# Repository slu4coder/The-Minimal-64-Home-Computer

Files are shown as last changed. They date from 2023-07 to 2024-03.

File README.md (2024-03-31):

# Legacy: Minimal 64 Home Computer

See https://github.com/slu4coder/Minimal-64x4-Home-Computer for the most recent version.

Quick note: This is a free and non-commercial project. I am in no way associated with any activies selling this as a product.
Any such activity represents a license violation. Individual licenses apply for hardware and software parts. Please refer to
appropriate documentations for detailed licensing information.



Here is my take on 80's home computer magic: The most computer from the least logic or the shortest way from TTL to Space Invaders.

Introductory videos: https://www.youtube.com/watch?v=3zGTsi4AYLw, https://www.youtube.com/watch?v=FJsnKu20ch8

Reference manual: https://docs.google.com/document/d/1e4hL9Z7BLIoUlErWgJOngnSMYLXjfnsZB9BtlwhTC6U/edit?usp=sharing

Visit my YouTube channel: https://www.youtube.com/channel/UCXYQcMpUBT3aaQKfmAVJNow

Like this project and want to give something back? https://www.paypal.me/carstenherting

FEATURES

● Only 56 74HCxx logic ICs, 1x 6C1008 SRAM, 4x 39SF0x0 FLASH, BUT NO MICROCONTROLLER!

● Textbook 'Von-Neumann' architecture, 8-bit data bus, 16-bit address bus, 24 control signals

● 64KB RAM, 512KB FLASH SSD with file system (format, load, save, dir, delete)

● Monochrome VGA output 400 x 240 pixels, PS/2, expansion slot and serial UART port

● 8MHz system clock, 6MHz CPU clock with 0.84Mips (2x Commodore 64)

● 128 instructions including conditional branching, subroutines, stack and word operations

● 2 data registers A, B plus two more "software" registers X, Y

● ALU supporting ADD, SUBTRACT, AND, OR with 3 flags (negative, carry and zero)

● Full native tool-chain: MinOS, text editor, assembler, fast Python-like interpreter 'MIN'

● Emulator, cross-assembler (Windows) and classic games (TETRIS clone, Space Invaders clone)

● Open-source emulators in JAVA/PROCESSING and JAVASCRIPT/p5.js https://editor.p5js.org/slu4coder/full/aOUivViNt

See "CHANGE LOG" for a brief summary of the relevant updates.
  
Have fun!

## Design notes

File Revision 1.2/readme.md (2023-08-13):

# Hardware Revision 1.2

For the bill of materials (BOM) please refer to the chapter 'Hardware' of the 'Minimal 64 Reference Manual': https://docs.google.com/document/d/1e4hL9Z7BLIoUlErWgJOngnSMYLXjfnsZB9BtlwhTC6U/edit?usp=sharing

Jim Bailey has also shared his MOUSER parts list.

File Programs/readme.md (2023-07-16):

# Native Software of the 'Minimal 64 Home Computer'

o '.asm' denotes assembly source code.

o '.min' denotes 'Min' source code.

o 'manual.txt' is displayed by the 'Minimal 64' upon entering 'show manual'.

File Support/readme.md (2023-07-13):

# Supporting Tool-Chain

o Cross-platform assemblers

o Emulators

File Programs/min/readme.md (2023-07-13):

# 'Min' Programs

'Min' is a Python-like high-level programming language running natively on the 'Minimal 64'.
The interpreter 'min.asm' assembly source code is located in the '../asm' section.

See 'Min's EBNF Language Definition.txt' for more information.

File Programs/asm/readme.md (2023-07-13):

# Assembly Programs

Assembly code (OS, native tool-chain, games, demos) written for the 'Minimal 64'.

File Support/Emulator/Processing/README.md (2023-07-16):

# Emulator (Java/Processing)

This is the portable 'Java/Processing' version of the 'Minimal 64 Home Computer' emulator.

The emulator is using German keyboard layout. For customizing do the following:

o Uncomment the first line of the 'keyPressed()' function in the source code: println(keyCode);

o Run the emulator and press any keys under question.

o Note the corresponding keyCodes printed out in Processing's console window.

o Identify the corresponding PS/2 scan codes (see section 'PS/2 Keyboard' in the 'Minimal 64 Reference Manual':
  https://docs.google.com/document/d/1e4hL9Z7BLIoUlErWgJOngnSMYLXjfnsZB9BtlwhTC6U/edit?usp=sharing

o Update the pre-defined 'keyScancodePairs' entries in the source code.

Have fun!

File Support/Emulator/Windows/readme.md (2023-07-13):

# Emulator (Win64 .exe)

On some graphic cards, 60Hz VSYNC is not detected correctly. In that case, set the frame rate manually to 60Hz from within your graphic card's control center.

Please note that the source code of the Windows/OpenGL version of the emulator (~5400 lines of code) is not available for download. If you are interested in the - amazingly simple - general principle of the emulator, please refer to the more readable but otherwise functionally identical Java/Processing version (~800 lines of code).

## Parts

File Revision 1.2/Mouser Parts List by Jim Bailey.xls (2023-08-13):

MINIMAL 64 HOME COMPUTER
Mouser # | Mfr. # | Manufacturer | Customer # | Description | RoHS | Lifecycle | Order Qty. | Price (USD) | Ext.: (USD)
538-90147-1106 | 90147-1106 | Molex |  | Headers & Wire Housings VERT SINGLE PCB 6P straight tail | RoHS Compliant |  | 4 | $2.07 | $8.28
535-1107741 | 1107741 | Aries Electronics |  | IC & Component Sockets OSCILLATOR FULL 4PIN | RoHS Compliant |  | 1 | $0.97 | $0.97
595-SN74HC00N | SN74HC00N | Texas Instruments |  | Logic Gates Quad 2-Input | RoHS Compliant |  | 4 | $0.68 | $2.72
595-CD74HCT132E | CD74HCT132E | Texas Instruments |  | Logic Gates Quad 2-In Schmit Trg | RoHS Compliant |  | 1 | $0.66 | $0.66
595-SN74HC574N | SN74HC574N | Texas Instruments |  | Flip Flops Tri-State Octal | RoHS Compliant |  | 4 | $0.77 | $3.08
595-SN74HC161N | SN74HC161N | Texas Instruments |  | Counter ICs 4-Bit Synch Binary | RoHS Compliant |  | 14 | $0.655 | $9.17
595-SN74HC245N | SN74HC245N | Texas Instruments |  | Bus Transceivers Tri-State Octal Bus | RoHS Compliant |  | 10 | $0.655 | $6.55
913-AS6C1008-55PCN | AS6C1008-55PCN | Alliance Memory |  | SRAM 1Mb, 2.7V-5.5V, 55ns 128K x 8 Asynch SRAM | RoHS Compliant |  | 1 | $3.75 | $3.75
595-SN74HC08N | SN74HC08N | Texas Instruments |  | Logic Gates Quad 2-Input. | RoHS Compliant |  | 3 | $0.67 | $2.01
595-SN74HC86N | SN74HC86N | Texas Instruments |  | Logic Gates Quad 2 Input | RoHS Compliant |  | 2 | $0.95 | $1.90
595-SN74HC04AN | SN74HC04AN | Texas Instruments |  | Inverters Hex Inverter | RoHS Compliant |  | 1 | $0.47 | $0.47
595-CD74HC595E | CD74HC595E | Texas Instruments |  | Counter Shift Registers 8-Bit Shift Register | RoHS Compliant |  | 2 | $1.37 | $2.74
595-SN74HC165N | SN74HC165N | Texas Instruments |  | Counter Shift Registers 8-Bit Parallel-Load | RoHS Compliant |  | 2 | $1.49 | $2.98
595-SN74HC590AN | SN74HC590AN | Texas Instruments |  | Counter ICs 3 State 8-Bit Binary | RoHS Compliant |  | 2 | $0.90 | $1.80
595-SN74HC32N | SN74HC32N | Texas Instruments |  | Logic Gates Quad 2-Input | RoHS Compliant |  | 4 | $0.64 | $2.56
594-MBB02070C4701FCT | MBB02070C4701FCT00 | Vishay |  | Metal Film Resistors - Through Hole .6w 4.7Kohms 1% | RoHS Compliant |  | 5 | $0.28 | $1.40
594-MBB02070C1500FRP | MBB02070C1500FRP00 | Vishay |  | Metal Film Resistors - Through Hole 150 OHM 1% 50PPM 3/5W | RoHS Compliant |  | 1 | $0.29 | $0.29
594-MBB02070C4700FRP | MBB02070C4700FRP00 | Vishay |  | Metal Film Resistors - Through Hole 0.6W 470ohm 1% 50ppm | RoHS Compliant |  | 16 | $0.242 | $3.87
594-MBB02070C3300FC1 | MBB02070C3300FC100 | Vishay |  | Metal Film Resistors - Through Hole .6w 330ohms 1% | RoHS Compliant |  | 8 | $0.42 | $3.36
75-1C10Z5U104M050B | 1C10Z5U104M050B | Vishay |  | Multilayer Ceramic Capacitors MLCC - Leaded 0.1uF 50volts Z5U 20% 2.5mm L/S | RoHS Compliant By Exemption |  | 26 | $0.149 | $3.87
774-MXO45-3C-16.0 | MXO45-3C-16M0000 | CTS |  | Standard Clock Oscillators 16.00000 MHz | RoHS Compliant |  | 1 | $3.76 | $3.76
688-SKHHAQ | SKHHAQA010 | Alps Alpine |  | Tactile Switches 6.0x6.0x4.3mm 260gf | RoHS Compliant |  | 1 | $0.403 | $10.08
575-393314 | 115-93-314-41-003000 | Mill-Max |  | IC & Component Sockets 14P TIN PIN GLD CONT | No |  | 17 | $1.63 | $27.71
575-11043320 | 110-43-320-41-001000 | Mill-Max |  | IC & Component Sockets 20P TIN PIN GLD CONT | RoHS Compliant By Exemption |  | 14 | $1.89 | $26.46
575-110433161 | 110-43-316-41-001000 | Mill-Max |  | IC & Component Sockets 16P TIN PIN GLD CONT | RoHS Compliant By Exemption |  | 25 | $1.53 | $38.25
575-11043632 | 110-43-632-41-001000 | Mill-Max |  | IC & Component Sockets 32P TIN PIN GLD CONT | RoHS Compliant By Exemption |  | 5 | $3.44 | $17.20
804-39SF010A7CPHE | SST39SF010A-70-4C-PHE | Microchip |  | NOR Flash 128K X 8 70ns | RoHS Compliant |  | 3 | $2.89 | $8.67
200-SSQ11601GD | SSQ-116-01-G-D | Samtec |  | Headers & Wire Housings Tiger Buy Socket Strip with Square Tails, 0.100" Pitch | RoHS Compliant |  | 1 | $7.34 | $7.34
523-L77HDE15SD1CH4R | L77HDE15SD1CH4R | Amphenol |  | D-Sub High Density Connectors D-SUB HIGH DENSITY | RoHS Compliant |  | 1 | $1.74 | $1.74
571-5749180-1 | 5749180-1 | TE Connectivity |  | Circular DIN Connectors 6P R/A W/ HOLDDOWN | RoHS Compliant |  | 1 | $2.15 | $2.15
200-SLW10601LD | SLW-106-01-L-D | Samtec |  | Headers & Wire Housings .100" Tiger Buy Low Profile Socket Strip | RoHS Compliant |  | 1 | $2.29 | $2.29
595-SN74HC193N | SN74HC193N | Texas Instruments |  | Counter ICs 4-Bit Sync UpDn Bnry | RoHS Compliant |  | 2 | $0.90 | $1.80
595-CD74HC283E | CD74HC283E | Texas Instruments |  | Logic Adder & Subtractor 4bit w/Fast-Carry | RoHS Compliant |  | 2 | $1.11 | $2.22
80-C315C201F3G5TA | C315C201F3G5TA | KEMET |  | Multilayer Ceramic Capacitors MLCC - Leaded 25V 200pF C0G 1% LS=2.54mm | RoHS Compliant |  | 1 | $1.09 | $1.09
517-929852-01-03-RA | 929852-01-03-RA | 3M |  | Headers & Wire Housings 6P STRT BRD MNT SKT 2 ROW 10MICRO" AU | RoHS Compliant |  | 1 | $2.10 | $2.10
594-MBB02070C7509FCT | MBB02070C7509FCT00 | Vishay |  | Metal Film Resistors - Through Hole 0.6W 75ohm 1% 50ppm | RoHS Compliant |  | 2 | $0.29 | $0.58
804-39SF0407CPHE | SST39SF040-70-4C-PHE | Microchip |  | NOR Flash 512K X 8 70ns | RoHS Compliant |  | 1 | $3.87 | $3.87
595-SN74HC166N | SN74HC166N | Texas Instruments |  | Counter Shift Registers 8-Bit Parallel-Load | RoHS Compliant |  | 1 | $1.49 | $1.49
eBay | 74HC4078 | Motorola |  | Logic Gates Logic 8-Input Or/Nor Gate | RoHS Compliant |  | 2 | ? | ?

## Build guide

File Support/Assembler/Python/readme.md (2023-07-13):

Minimalistic cross-platform assembler written in Python.

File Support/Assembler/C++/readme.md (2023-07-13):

Cross-platform assembler written in C++.

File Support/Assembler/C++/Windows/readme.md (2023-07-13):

Cross-platform assembler written in C++ running on Windows.

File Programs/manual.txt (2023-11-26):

-------------------------------------------------
M I N I M A L  6 4  HOME COMPUTER MANUAL  by slu4
-------------------------------------------------

Welcome to the 'MINIMAL 64'. This file provides a
brief introduction on how to use this computer.

1. OS COMMANDS (1/2)

The 'MinOS' operating system loads and executes
any entered filename as a separate program. So
any file can be considered an 'OS command'. MinOS
comes with the following built-in commands
(parameters in square [] brackets are optional):

'run' [<x>] starts execution at hex address <x>.

'dir' displays the file directory of the SSD.

'del <file>' deletes a file on the SSD.

'show <file>' displays a text file page by page.

'format' formats SSD user area (banks 3..127).

'defrag' frees up unused SSD storage fragments.

'memset <x> <y> <d>' fills RAM <x>..<y> with <d>.%
1. OS COMMANDS (2/2)

'mon [<x>]'  starts a memory monitor [at <x>].
  ESC        exits the monitor to the OS prompt.
  <x>        changes the monitor address to <x>.
  [<x>].<y>  displays an address range.
  :<d>[ <d>] deposits <d> at current address++.
  #<x>       activates SSD bank <x>, 0x80 for RAM
  <x>, <y>, <d> can be a HEX value '0' to 'ffff'.

'memmove <x> <y> <z>' moves memory area <x>..<y>
  to <z>. Source and destination may overlap.

'receive' receives an 'Intel HEX File' you paste
  via UART terminal and writes the data into RAM.

'save <x> <y> <name>' saves memory area <x>..<y>
  under the filename <name> onto the SSD.

'flash' updates the OS 'in-situ'. The user's SSD
  area remains unchanged. Full update procedure:

  o Assemble the OS with 'asm os.asm' on your PC.
    This will output a 'HEX file' to the console.
  o On the Minimal, type 'memset 0 2fff ff ENTER'
    to clear the RAM.
  o Type 'receive ENTER' and paste the HEX file
    image to the Minimal's RAM as serial input.
  o On the Minimal, type 'flash ENTER' and reset.%
2. MEMORY MAP

0x0000..0x0fff 4KB of selected FLASH bank or RAM:

               bank 0: OS kernel & API image
               bank 1: OS data (charset, tables)
               bank 2: protected core OS commands
               bank 3..127: user SSD area
               bank >= 128: RAM (FLASH disabled),

0x1000..0xafff 40KB free RAM

0xb000..0xbcff 3KB OS kernel & API
0xbcb0..0xbccd 30 bytes of OS variables
0xbcce..0xbcff 50 bytes of OS line input buffer
0xbd00..0xbeff 512 bytes of OS 'command memory'

0xbf00..0xbfff reserved for expansions cards

0xc000..0xfeff 16KB video RAM (252 x 64 bytes)
0xc30c         start of 400 x 240 pixels viewport

0xff00         CPU X register
0xff01         CPU Y register
0xff02..0xfffe CPU stack memory
0xffff         CPU stack pointer LSB%
3. TEXT EDITOR 'edit [<file>]'

The text editor resides in RAM 0x0000..0x0fff.
Text data is stored from address 0x1000 onwards.
Once loaded, the editor can be restarted by
typing 'run', preserving your text document.

CTRL q  or ESC quits the editor.
CTRL n  Starts a new document.

CTRL l  Dialog line to input a filename to load.
CTRL s  Dialog line to save the text as a file.

CTRL a  Marks the start of a text block.
CTRL x  Marks the end of a text blocks and cuts
        out the marked text block to clipboard.
CTRL c  Marks the end of a text block and copies
        the marked text block to clipboard.
CTRL v  Inserts a text block from clipboard at
        the current cursor position.

CTRL r  Receives text via UART and inserts it at
        the current position. Press ESC to end.
CTRL t  Transmits the current text file via UART.%
4. HIGH-LEVEL LANGUAGE 'min'

MIN is a fast high-level Python-like interpreted
programming language. 'min <file>' executes your
program from SSD. 'min' directly starts a program
at 0x1000.
MIN occupies the RAM area 0x8000..0x9fff and uses
0xa000..0xafff for runtime data storage.

The following list of features and commands will
get you started (for more information see the
exact language definition in EBNF):

o Python-style code block indentation (2 SPACES)
o control structure 'if-elif-else', 'while-break'
o variables with C-style static explicit typing
o data types 'char' (8-bit) and 'int' (16-bit)
o local and global variables, @ address operator
o 'def-return', C-style '&' variable references
o 'call(..)' for assembly/API routine integration
o full expression handling including '+=', '-='
o bitwise/logical operators 'and/or/xor/not'
o [..|..] element access and '_' concatenation
o decimal and HEX '0xffff' numbers, ".." strings
o print(..) for text and decimal number output
o 'use "<library>"' for recursive file import
o 'std.min' library implements: pos, rnd, clear,
   line, rect, dot, str, len, strcmp, key, etc.%
5. ASSEMBLER 'asm' (1/2)

ASM is MINIMAL's native assembler. To assemble
a sourcefile <file> from SSD, type 'asm <file>'.
In case the source text already resides in RAM
you can simply assemble with 'asm'. ASM uses the
RAM area 0x9000..0x9fff. Range 0xa000..0xafff
holds label definitions during assembly.

Note: While assembling a program, ASM uses two
pointers: a memory counter (MC) and a program
counter (PC). Data is always emitted to MC.
Labels are defined with respect to the PC.
Default for MC and PC is address 0x8000.

#emit       starts data emission to MC
#mute       mutes data emission to MC, but
            keeps updating PC while assembling
*           alias for current MC address value
#org <addr> sets PC, sets MC only when emitting

o Write mnemonics in capital letters (e.g., LDI).
o Write HEX numbers in lower case (e.g., 0xff).
o Separate elements with a space and/or comma.%
5. ASSEMBLER 'asm' (2/2)

label:      defines a label as the current PC
; comment   makes the rest of the line a comment
<label      LSB operator (at element start only)
>label      MSB operator (at element start only)
0x0a, 123   HEX and DEC byte values
0xff10      HEX word (little-endian) = 0x10, 0xff
'A'         character, equivalent to 65 or 0x41
'AAA', 0    string, equivalent to 65, 65, 65, 0
addr+off-1  handling of simple expressions
*           alias for the value of current MC

Example:

#org 0x8000             ; sets start address
            LDI 0xff    ; loads 0xff into A
            STA 0xc30c  ; deposits A in VRAM
            JPA 0xb003  ; jumps back to OS prompt%
6. CPU INSTRUCTION SET (1/8)

INS     = instruction mnemonic  | -   = unchanged
HX      =  hexadecimal opcode   | ?   = undefined
OP SIZE =  operand type / size  | R   = result
                                | M   = MSB
A       =  accumulator          | imm = immediate
NCZ     =  ALU flags N, C, Z    | abs = absolute
CL      =  clock cycles         | off = offset
PC      =  program counter      | rel = relative

INS|HX|DESCRIPTION       |TARGET|OP SIZE|A|NCZ|CL
---+--+------------------+------+-------+-+---+--
NOP|00|No operation      |-     |-     0|-|---|16
BNK|01|Set SSD bank      |BANK  |A     0|-|---| 4
BFF|02|Switch off SSD    |BANK  |-     0|-|---| 4
WIN|03|Wait for input    |-     |-     0|?|???| -
INP|04|UART input/clear  |A     |-     0|R|???| 5
INK|05|PS/2 input/clear  |A     |-     0|R|???| 5
OUT|06|UART output       |UART  |A     0|-|100| 4
NOT|07|Bitwise NOT       |A     |-     0|R|---| 6
NEG|08|Negate            |A     |-     0|R|RZR| 6
INC|09|Increment         |A     |-     0|R|RRR| 5
DEC|0a|Decrement         |A     |-     0|R|RRR| 5
CLC|0b|Clear carry in    |-     |-     0|-|100| 5
SEC|0c|Set carry in      |-     |-     0|-|011| 5%
6. CPU INSTRUCTION SET (2/8)

INS|HX|DESCRIPTION       |TARGET|OP SIZE|A|NCZ|CL
---+--+------------------+------+-------+-+---+--
LSL|0d|Logic shift left 1|A     |-     0|R|RRR| 5
LL2|0e|Logic shift left 2|A     |-     0|R|RRR| 6
LL3|0f|Logic shift left 3|A     |-     0|R|RRR| 7
LL4|10|Logic shift left 4|A     |-     0|R|RRR| 8
LL5|11|Logic shift left 5|A     |-     0|R|RRR| 9
LL6|12|Logic shift left 6|A     |-     0|R|RRR|10
LL7|13|Logic shift left 7|A     |-     0|R|RRR|11
LSR|14|Logic shift right |A     |-     0|R|RRR|12
---+--+------------------+------+-------+-+---+--
ROL|15|Rotate left 1     |A     |-     0|R|RRR| 5
RL2|16|Rotate left 2     |A     |-     0|R|RRR| 6
RL3|17|Rotate left 3     |A     |-     0|R|RRR| 7
RL4|18|Rotate left 4     |A     |-     0|R|RRR| 8
RL5|19|Rotate left 5     |A     |-     0|R|RRR| 9
RL6|1a|Rotate left 6     |A     |-     0|R|RRR|10
RL7|1b|Rotate left 7     |A     |-     0|R|RRR|11
ROR|1c|Rotate right      |A     |-     0|R|RRR|12%
6. CPU INSTRUCTION SET (3/8)

INS|HX|DESCRIPTION       |TARGET|OP SIZE|A|NCZ|CL
---+--+------------------+------+-------+-+---+--
LDI|1d|Load from         |A     |imm   1|R|---| 5
ADI|1e|Add               |A     |imm   1|R|RRR| 5
SBI|1f|Subtract          |A     |imm   1|R|RRR| 5
ACI|20|Add with carry in |A     |imm   1|R|RRR| 5
SCI|21|Sub with carry in |A     |imm   1|R|RRR| 5
CPI|22|Compare           |A     |imm   1|-|RRR| 5
ANI|23|Bitwise AND       |A     |imm   1|R|---| 5
ORI|24|Bitwise OR        |A     |imm   1|R|---| 5
XRI|25|Bitwise XOR       |A     |imm   1|R|---|12
---+--+------------------+------+-------+-+---+--
JPA|26|Jump to           |PC    |abs   2|-|---| 5
LDA|27|Load from         |A     |abs   2|R|---| 7
STA|28|Store A           |byte  |abs   2|-|---| 7
ADA|29|Add               |A     |abs   2|R|RRR| 8
SBA|2a|Subtract          |A     |abs   2|R|RRR| 8
ACA|2b|Add with carry in |A     |abs   2|R|RRR| 8
SCA|2c|Sub with carry in |A     |abs   2|R|RRR| 8
CPA|2d|Compare           |A     |abs   2|-|RRR| 8
ANA|2e|Bitwise AND       |A     |abs   2|R|---| 8
ORA|2f|Bitwise OR        |A     |abs   2|R|---| 8
XRA|30|Bitwise XOR       |A     |imm   1|R|---|15%
6. CPU INSTRUCTION SET (4/8)

INS|HX|DESCRIPTION       |TARGET|OP SIZE|A|NCZ|CL
---+--+------------------+------+-------+-+---+--
JPR|31|Jump to           |PC    |rel   2|-|---| 8
LDR|32|Load from         |A     |rel   2|R|---|10
STR|33|Store A           |byte  |rel   2|-|---|10
ADR|34|Add               |A     |rel   2|R|RRR|11
SBR|35|Subtract          |A     |rel   2|R|RRR|11
ACR|36|Add with carry in |A     |rel   2|R|RRR|11
SCR|37|Sub with carry in |A     |rel   2|R|RRR|11
CPR|38|Compare           |A     |rel   2|-|RRR|11
ANR|39|Bitwise AND       |A     |rel   2|R|---|11
ORR|3a|Bitwise OR        |A     |rel   2|R|---|11%
6. CPU INSTRUCTION SET (5/8)

INS|HX|DESCRIPTION       |TARGET|OP SIZE|A|NCZ|CL
---+--+------------------+------+-------+-+---+--
CLB|3b|Clear             |byte  |abs   2|-|---| 8
NOB|3c|Bitwise NOT       |byte,A|abs   2|R|---| 9
NEB|3d|Negate            |byte,A|abs   2|R|RZR| 9
INB|3e|Increment         |byte,A|abs   2|R|RRR| 9
DEB|3f|Decrement         |byte,A|abs   2|R|RRR| 9
ADB|40|Add               |byte,A|abs   2|R|RRR| 8
SBB|41|Subtract          |byte,A|abs   2|R|RRR| 9
ACB|42|Add with carry in |byte,A|abs   2|R|RRR| 8
SCB|43|Sub with carry in |byte,A|abs   2|R|RRR| 9
ANB|44|Bitwise AND       |byte,A|abs   2|R|---| 8
ORB|45|Bitwise OR        |byte,A|abs   2|R|---| 8
LLB|46|Shift left        |byte,A|abs   2|R|RRR| 8
LRB|47|Shift right       |byte,A|abs   2|R|RRR|15
RLB|48|Rotate left       |byte,A|abs   2|R|RRR| 8
RRB|49|Rotate right      |byte,A|abs   2|R|RRR|15%
6. CPU INSTRUCTION SET (6/8)

INS|HX|DESCRIPTION       |TARGET|OP SIZE|A|NCZ|CL
---+--+------------------+------+-------+-+---+--
CLW|4a|Clear             |word  |abs   2|-|---| 9
NOW|4b|Bitwise NOT       |word,A|abs   2|M|---|11
NEW|4c|Negate            |word,A|abs   2|M|MZM|11
INW|4d|Increment         |word,A|abs   2|M|MMM|11
DEW|4e|Decrement         |word,A|abs   2|M|MMM|12
ADW|4f|Add               |word,A|abs   2|M|MMM|11
SBW|50|Subtract          |word,A|abs   2|M|MMM|12
ACW|51|Add with carry in |word,A|abs   2|M|MMM|11
SCW|52|Sub with carry in |word,A|abs   2|M|MMM|12
LLW|53|Shift left        |word,A|abs   2|M|MMM|10
RLW|54|Shift right       |word,A|abs   2|M|MMM|10
---+--+------------------+------+-------+-+---+--
JPS|55|Jump to subroutine|PC    |abs   2|?|---|14
RTS|56|Return from sub   |PC    |-     0|-|---|12
PHS|57|Push on stack     |stack |-     0|-|---|11
PLS|58|Pull from stack   |A     |-     0|R|---| 7
LDS|59|Load from stack   |A     |off   1|R|---| 8
STS|5a|Store A on stack  |stack |off   1|-|---|15%
6. CPU INSTRUCTION SET (7/8)

INS|HX|DESCRIPTION       |TARGET|OP SIZE|A|NCZ|CL
---+--+------------------+------+-------+-+---+--
BNE|5b|Branch on not eq  |PC    |abs   2|-|---| 5
BEQ|5c|Branch on equal   |PC    |abs   2|-|---| 5
BCC|5d|Branch on C clear |PC    |abs   2|-|---| 5
BCS|5e|Branch on C Set   |PC    |abs   2|-|---| 5
BPL|5f|Branch on plus    |PC    |abs   2|-|---| 5
BMI|60|Branch on minus   |PC    |abs   2|-|---| 5
BGT|61|Branch greater    |PC    |abs   2|-|---| 5
BLE|62|Branch less or eq |PC    |abs   2|-|---| 5
---+--+------------------+------+-------+-+---+--
TAX|63|Transfer A to X   |X     |-     0|-|---| 6
TXA|64|Transfer X to A   |A     |-     0|R|---| 6
TXY|65|Transfer X to Y   |Y     |-     0|-|---| 7
LXI|66|Load from         |X     |imm   1|-|---| 7
LXA|67|Load from         |X     |abs   2|-|---|10
LTX|68|Load from table * |A     |abs+X 2|R|???|12
INX|69|Increment         |X     |-     0|R|RRR| 7
DEX|6a|Decrement         |X     |-     0|R|RRR| 7
ADX|6b|Add               |A     |-     0|R|RRR| 7
SBX|6c|Subtract          |A     |-     0|R|RRR| 7
CPX|6d|Compare           |A     |-     0|R|RRR| 7
ANX|6e|Bitwise AND       |A     |-     0|R|---| 7
ORX|6f|Bitwise OR        |A     |-     0|R|---| 7
XRX|70|Bitwise XOR       |A     |-     0|R|---|13%
6. CPU INSTRUCTION SET (8/8)

INS|HX|DESCRIPTION       |TARGET|OP SIZE|A|NCZ|CL
---+--+------------------+------+-------+-+---+--
TAY|71|Transfer A to Y   |Y     |-     0|-|---| 7
TYA|72|Transfer Y to A   |A     |-     0|R|---| 7
TYX|73|Transfer Y to X   |X     |-     0|-|---|10
LYI|74|Load from         |Y     |imm   1|-|---| 8
LYA|75|Load from         |Y     |abs   2|-|---|11
LTA|76|Load from table * |A     |abs+A 2|R|???| 7
INY|77|Increment         |Y     |-     0|R|RRR| 8
DEY|78|Decrement         |Y     |-     0|R|RRR| 8
ADY|79|Add               |A     |-     0|R|RRR| 8
SBY|7a|Subtract          |A     |-     0|R|RRR| 8
CPY|7b|Compare           |A     |-     0|R|RRR| 8
ANY|7c|Bitwise AND       |A     |-     0|R|---| 8
ORY|7d|Bitwise OR        |A     |-     0|R|---| 8
XRY|7e|Bitwise XOR       |A     |-     0|R|---|14
---+--+------------------+------+-------+-+---+--
HLT|7f|Halt CPU          |-     |-     0|?|???| -

  * takes 2 more cycles crossing a page boundary%
7. HARDWARE SPECIFICATION

System clock rate............................8MHz

Effective CPU clock rate.....................6MHz

Supply voltage range.................4.3V to 5.5V

Supply current.......140mA @ 4.3V to 200mA @ 5.5V

UART bit rate.............................250Kbps

UART format 1 start bit, 8 data bits, 2 stop bits
            no parity bit, newline LF (0x0a)

UART transmit delay.....................10ms/line

Set the terminal emulation to 50 x 30 characters.

                END OF DOCUMENT

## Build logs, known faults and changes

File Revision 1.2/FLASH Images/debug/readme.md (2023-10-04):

These FLASH images might by helpful to debug your board in case it won't start up properly.

'debug' writes a back and a white 8x8 pixel square into VRAM's upper left corner
        prior to starting the bootloader.
        This might show you a 'first sign of life' in case the OS doesn't boot.
'debug2' writes 0xff contiguously into VRAM starting from the left upper corner
         for each byte copied from FLASH to RAM during bootstrapping.
         This lets you monitor the boot process in case the OS doesn't boot.

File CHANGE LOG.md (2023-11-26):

# CHANGE LOG

Nov 26 2023: Extending the reserved memory range for expansion cards

The memory range reserved for expansion cards is extended to a full page 0xbf00 - 0xbfff. This involves changes in the documentation (reference manual, manual.txt) and also makes relocating some OS variables (e.g. cursor position _XPos and _YPos) necessary, forcing an update of all software using these variables ;-) as well as the "standard" image 'flash.bin'.

Oct 28 2023: Microcode 1.22 update:

o The instruction LTX replaces LAX but remains functionally identical.

o The instruction LTA replaces LAY and now uses the accumulator A as table index rather than the Y register.

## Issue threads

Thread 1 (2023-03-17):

missing kicad file

denjhang, 2023-03-17:
I've always been a big fan of the minimal series and would love to build a minimal 64

slu4coder, 2023-03-18:
KiCAD files will be released and added to the repo as my video series progresses.

Closed 2023-03-18.

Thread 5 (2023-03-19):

SST39SF040A

lindoran, 2023-03-19:
In going over the BOM (I am trying to figure out sourcing some of the parts leading up to the PCB release) is the
SST39SF040 going to be ok?

https://www.mouser.com/ProductDetail/Microchip-Technology-Atmel/SST39SF040-70-4C-PHE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

I am thinking possibly yes. -- I am having a very difficult time finding this one from even a sketchy source

Thanks for your time.

Dave

denjhang, 2023-03-26:
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

I don't think this is a problem because I already have several hundred SST39SF040, this FlashROM is arguably one of the most commonly used memory chips in the retro computer world. You can try AliExpress (beware of fakes).

lindoran, 2023-03-26:
Thanks :)

On Sun, Mar 26, 2023, 11:18 AM Denjhang Liu ***@***.***>
wrote:

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

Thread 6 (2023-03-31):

way to change the keyboard layout (at least on the emulator)

lindoran, 2023-03-31:
I know the whole point of the computer is to be minimal and things like a new keyboard layout would make the whole build less minimal but the UK layout moves the quotation marks  over the two (among other things). Would it be possible to allow for other keyboard layouts inside the emulator?  To allow for a us or standard 101 keyboard layout?

slu4coder, 2023-03-31:
Hi, Dave,
the whole issue of different keyboard layouts isn't easy for me to solve, since I can't test. Here are a few thoughts:

On the Minimal 64 hardware the PS2 scancodes are translated into Minimal keycodes (ASCII wherever possible) via a lookup table as part of MinOS. You can easily change this lookup table inside os.asm, re-assemble and update the OS via 'flash' as described in the manual. I already provide a German and US keyboard table snippet in the repo.

On the emulator things get more complicated. Your (local) OS will send OpenGL keycodes to the application. The application translates these into PS2 scancodes and finally MinOS translates them back into Minimal keycodes as described above. Any mismatch and you won't find your quotation marks.

At this stage I haven't exposed the GLFW keycode -> PS2 scancode table of the emulator. I'll look into it.

lindoran, 2023-03-31:
Thank you for such a quick response :) I figured it was complicated but at
least there's a live hardware fix. I wonder if I can play around with the
settings in wine to mimic a UK keyboard, that would at least fix the issue
on linux, it's a hack but it might work out as a fix that leads to the
solution. At least knowing how that works makes trying to find a work
around more straight forward.  I will test this weekend and let you know

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

slu4coder, 2023-04-10:
I've added a simple (yet fully functional) Java/Processing version of the emulator. This should solve any portability issues.
Let me know what you think.

Closed 2023-07-07.

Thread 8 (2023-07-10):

What is the FF flag?

michaelkamprath, 2023-07-10:
The microcode definitions for the X, Y, and stack interactions have a microcode flag called `FF`. I don't readily see in the schematic that that flag is. I suspect it is just a conceptual placeholder that does nothing, thus the data base has a 0xFF value on it due to the pull up resistors, but we don't have access to the microcode compiler to confirm that. Any insight here would be appreciated.

slu4coder, 2023-07-10:
FF is not a physical control signal or flag. As you have guessed correctly, I use it as a placeholder for "all control signals inactive". Whenever you see "FF" in the microcode, 0xFF (-1) is present at the bus. As trivial as this feature looks, "FF" appears in 139 microcode positions across the entire instruction set and is *the* key for most if not all of the advanced instructions of the CPU.

Closed 2023-07-10.

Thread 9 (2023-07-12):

AS6C1008 SRAM "64KB"?

michaelkamprath, 2023-07-12:
The BOM in the user manual for the Minimal 64 describes U13 as `AS6C1008_SRAM_64KB`, however, the `AS6C1008` is a 128K RAM chip. Is the "64KB" in the BOM description a typo, the wrong chip, or is it just indicating how much of the `AS6C1008` is actually being used?

slu4coder, 2023-07-12:
Thanks for pointing out this potential pitfall. I am indeed using AS6C1008, i. e. a 128K SRAM chip.

The Minimal, being a 16-bit machine, only addresses 64KB of it.
In the schematic A16 (Pin 2 of U13) is grounded. I will correct it in the BOM to avoid confusion.

Closed 2023-07-12.

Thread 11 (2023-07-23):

Is there a Minimal 64 Home Computer forum

denjhang, 2023-07-23:
I'm about to build hardware for Minimal 64, like last year's Minimal UART CPU, is there a forum? Recently I found out that the forum for Minimal UART CPU is closed.

slu4coder, 2023-07-23:
Hi, great to hear you are going to give the 'Minimal 64' a try, too. It is basically a Minimal UART on steroids ;-) As of today, I am not planning to continue the forum for the Minimal 64. It is just too confusing for me as a one-man show. Let's either use GitHub issues or plain old email. Don't forget to send me a picture of your build to secure your place and serial number in the 'Gallery' section of the Minimal 64 Manual :-)

michaelkamprath, 2023-07-23:
@slu4coder If I might suggest, you could enable GitHub discussions for this repository. It's a discussion board for this repository. The issue with issues is that they are design to be "closed" and once closed, it's hard for people to learn from the discussion.

See this: https://github.com/features/discussions

slu4coder, 2023-07-23:
GitHub discussions activated :-)

Closed 2023-07-23.

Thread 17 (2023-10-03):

Improve VGA signal quality a bit

fdziarmagowski, 2023-10-03:
There are visible vertical lines when displaying content with lots of "white" pixels.
I found that adding an additional decoupling capacitor (100n) to U44 directly to pins 1 and 16 improved the picture quality in such case.
One could use a socket with a with a decoupling capacitor to avoid changes to the layout, so this is more like a feature request than a bug report.

Thanks!

slu4coder, 2023-10-04:
On my two boards, I cannot confirm any vertical lines in the output with the present design.
U44 is indeed the 74HC166 shift register generating the pixel stream for the VGA monitor. A 100nF cap doesn't hurt.
But, I'd first investigate a possible problem with the supply voltage on your board, Fryderyk, probably caused by a bad IC.
In such a case, the 100nF cap would just cover up a deeper problem.

fdziarmagowski, 2023-10-04:
I'm at ~180 mA with keyboard connected. As you know my PCB has some other issues (which can be related), but power draw is not really an issue. I don't want to "cross post" the issues.
Thanks for looking at this small issue!

Closed 2023-10-04.

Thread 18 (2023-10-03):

"show" output incomplete

fdziarmagowski, 2023-10-03:
Try "show lines.min", in the first line "se" instead of "use" will be shown.

slu4coder, 2023-10-04:
Presently, 'show' is intended to display text documents *only* in the special format (% for page breaks) used by 'manual'. 'show' should not be used to display arbitrary text data, e. g. source code. Please use 'edit <textfile>' instead.

I know, this is a bit counter-intuitive and I might improve the 'show' command in the future.

slu4coder, 2023-10-04:
I have rewritten the 'show' command to both display source files and the manual page-wise in an intuitive way. The files manual.txt, os.asm and flash.bin have been updated.

fdziarmagowski, 2023-10-04:
This is awesome! I just translated "show" to "cat" at my fingertips, automagically expecting it will work on any file. This blind assumption was of course incorrect.

slu4coder, 2023-10-04:
If you want to change the names of OS commands in os.asm sourcecode, always make sure you edit the file header correctly, i. e. inserting zeros after the name when you make it shorter helps 😀

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

Closed 2023-10-04.

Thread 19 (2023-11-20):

Newly soldered Minimal64 not working

denjhang, 2023-11-20:
I just finished soldering a Minimal64. I used 628128 instead of as6c1008. I found that my Minimal64 currently cannot be turned on. Nothing is output on the VGA and no characters appear on the UART.

denjhang, 2023-11-20:
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

denjhang, 2023-11-20:
I tried pressing the reset button and the UART gave me a garbled code every time it reset.

denjhang, 2023-11-20:
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

slu4coder, 2023-11-23:
Hi denjhang,
welcome to this corner of the internet. Your Minimal 64 looks great. Sad to hear that it refuses to work. I have never tried the RAM IC you mention but it seems to be pin compatible to the one I have used. From afar, it is not easy to give you good advice here. I would start to re-inspect every soldering joint first, then look for any bent pins (happened to me the other day), then re-check the type and orientation of all ICs. Does the UART send a specific number of bytes upon pressing reset? It is supposed to send "READY." plus a line feed, 7 chars in total. For debugging there is an image you can try and burn into the FLASH for testing.

denjhang, 2023-11-24:
I made sure I had correctly burned the ROM into the chip, I'm using a TL866II+.
I have replaced AS6C1008, and I have also replaced all 74 chips with original chips. However, nothing happens when I press the reset button this time.

denjhang, 2023-11-24:
https://github.com/slu4coder/The-Minimal-64-Home-Computer/tree/main/Revision%201.2/FLASH%20Images/debug

It looks like there is a debug ROM here that I can try.

denjhang, 2023-11-24:
I thought I should make another Minimal UART CPU and Gigatron to verify the usability of the 74 chip.

slu4coder, 2023-11-25:
It can be helpful to only use new ICs from "trusted" sources rather than used ones or older ICs of unclear origins. This can save a lot of trouble. It might be a good idea to burn the debug FLASH images for testing to make sure the CPU shows basic signs of life. But to make any sort of progress here, we need to collect more data, make some additional measurements. I suggest to take a look at the following:

1) Make sure that all ICs see a nice and stable supply voltage of 5V. Measure the supply voltage on of each IC (top right pin).
2) Make sure the Clock oscillator outputs a proper 16MHz signal.
3) Make sure you have valid 8MHz, 4MHz and 2MHz clock signals (U50, pins 14, 13, 12).
4) Take a look at ~VSYNC (act low every 16.7ms) and ~HSYNC (act low every 32µs).

Then you should be able to see at least a stable (maybe still random) video output on you VGA display since the VGA is quite independent of the CPU.

Only then I'd recommend trying the debug images. Good luck!

slu4coder, 2023-11-25:
denjhang, since you are not requesting to change a certain specific issue here, let's continue trouble-shooting in the discussions section. Please start a new discussion there if you need further assistance.

Closed 2023-11-25.

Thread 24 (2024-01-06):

Is it possible to provide a US keyboard layout version of the Flash ROM file?

denjhang, 2024-01-06:
I want to change the keyboard layout, I use US keyboard, but when I use receive, the transmission always goes wrong.
So I hope to burn the US keyboard layout into ROM directly through the programmer instead of using UART.

slu4coder, 2024-01-06:
I have uploaded a version of 'flash.bin' with pre-installed US keyboard layout I have renamed to  'flash_us.bin'.

If you find yourself unable to update via UART there is still a problem within you circuit worth debugging. On my system, upload via UART does not produce any checksum errors.

Closed 2024-01-06.

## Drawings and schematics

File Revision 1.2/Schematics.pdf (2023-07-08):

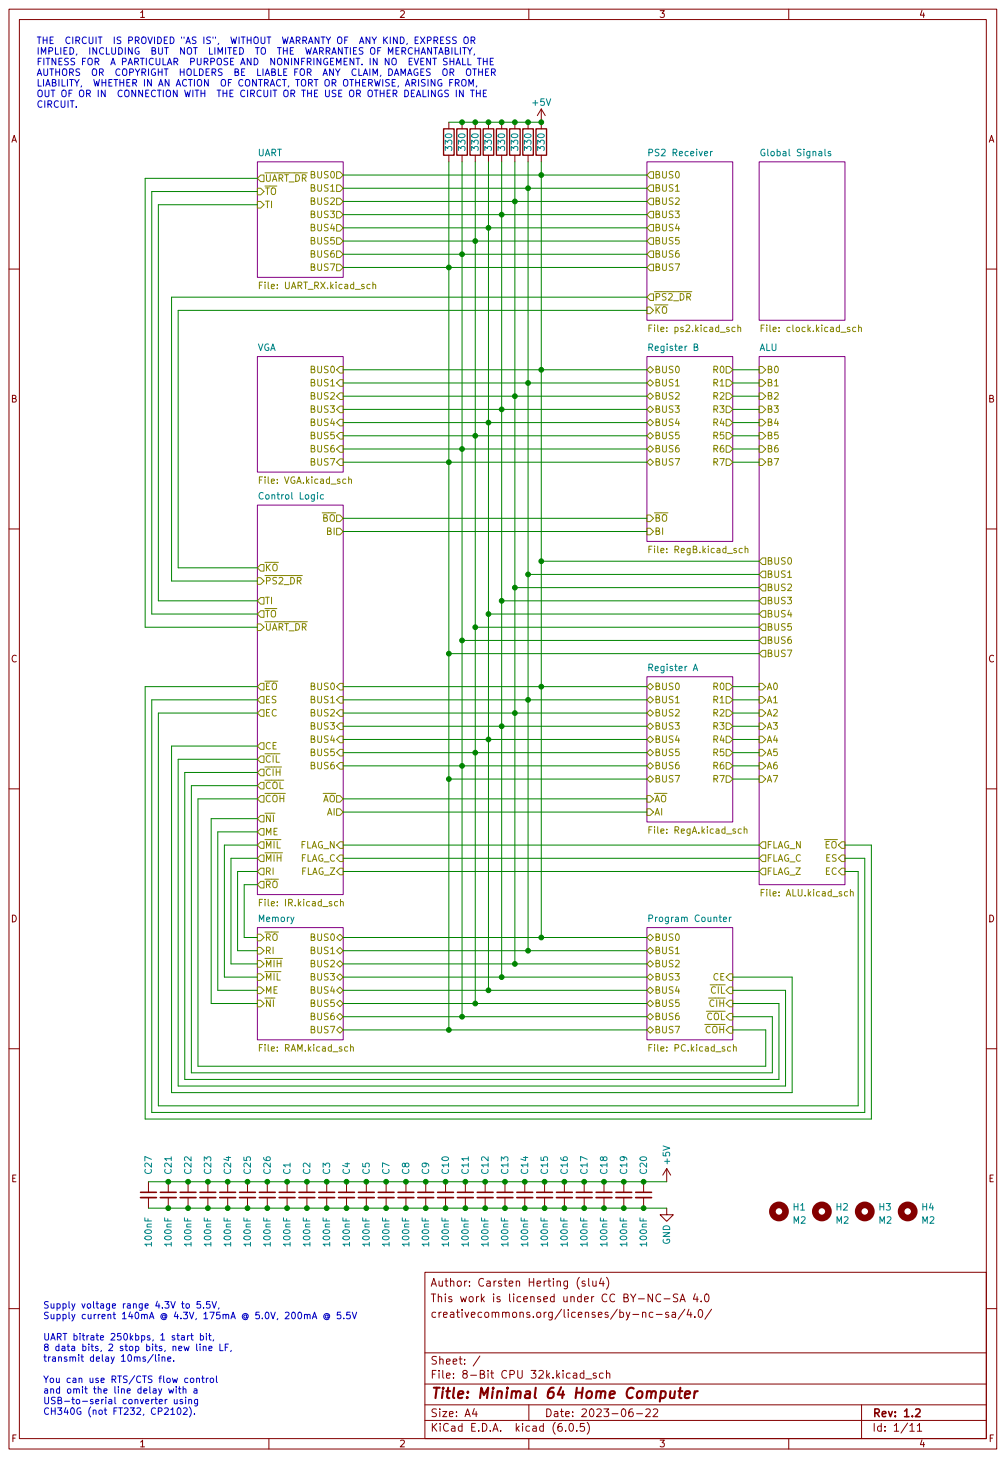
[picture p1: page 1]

THE CIRCUIT IS PROVIDED "AS IS", WITHOUT WARRANTY OF ANY KIND, EXPRESS OR
IMPLIED, INCLUDING BUT NOT LIMITED TO THE WARRANTIES OF MERCHANTABILITY, FITNESS FOR A PARTICULAR PURPOSE AND NONINFRINGEMENT. IN NO EVENT SHALL THE

AUTHORS OR COPYRIGHT HOLDERS BE LIABLE FOR ANY CLAIM, DAMAGES OR OTHER
LIABILITY, WHETHER IN AN ACTION OF CONTRACT, TORT OR OTHERWISE, ARISING FROM, OUT OF OR IN CONNECTION WITH THE CIRCUIT OR THE USE OR OTHER DEALINGS IN THE CIRCUIT.

Global Signals File: clock.kicad_sch BUS0 BUS1 BUS2 BUS3 BUS4 BUS5 BUS6 BUS7 ~{TO}

~{PS2_DR}BUS6 Control Logic File: IR.kicad_sch BUS0 BUS1 BUS2 BUS3 BUS4 BUS5 BUS6 BUS7 ~{RO} ME
~{UART_DR} FLAG_Z

Program Counter File: PC.kicad_sch BUS0 BUS1 BUS2 BUS3 BUS4 BUS5AI ~{AO} BI ~{BO}

~{MIL} RI Memory File: RAM.kicad_sch

File: 8-Bit CPU 32k.kicad_sch Sheet: / creativecommons.org/licenses/by-nc-sa/4.0/ This work is licensed under CC BY-NC-SA 4.0 Author: Carsten Herting (slu4)

Supply voltage range 4.3V to 5.5V,
Supply current 140mA @ 4.3V, 175mA @ 5.0V, 200mA @ 5.5V

UART bitrate 250kbps, 1 start bit,
8 data bits, 2 stop bits, new line LF,
transmit delay 10ms/line. You can use RTS/CTS flow control and omit the line delay with a

Id: 1/11 Title: Minimal 64 Home Computer

USB-to-serial converter using
CH340G (not FT232, CP2102).

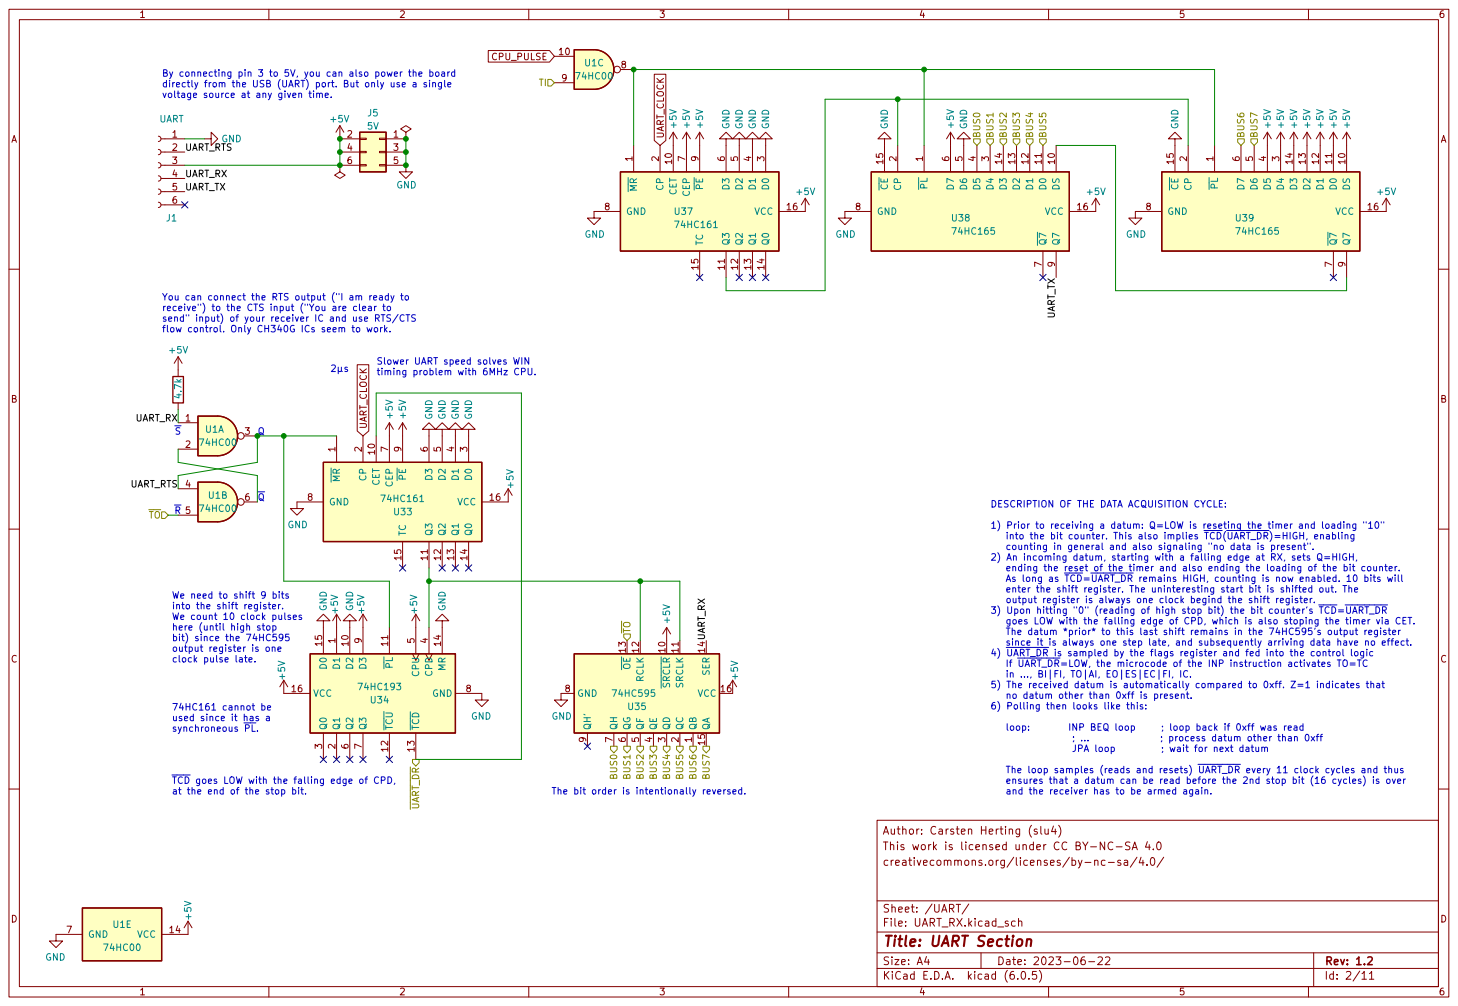
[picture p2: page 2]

voltage source at any given time. Q
UART_RTS UART_RX UART_TX UART_RTS

By connecting pin 3 to 5V, you can also power the board
directly from the USB (UART) port. But only use a single

You can connect the RTS output ("I am ready to
receive") to the CTS input ("You are clear to
send" input) of your receiver IC and use RTS/CTS
flow control. Only CH340G ICs seem to work.
~{Q} 74HC161 cannot be

Slower UART speed solves WIN

~{S} We need to shift 9 bits

1 CET 10 Q3 11 Q2 12 Q1 13 Q0 14 TC 15 VCC 16 CP

into the bit counter. This also implies ~{TCD}(~{UART_DR})=HIGH, enabling
counting in general and also signaling "no data is present".
2) An incoming datum, starting with a falling edge at RX, sets Q=HIGH,
ending the reset of the timer and also ending the loading of the bit counter.
As long as ~{TCD}=~{UART_DR} remains HIGH, counting is now enabled. 10 bits will
enter the shift register. The uninteresting start bit is shifted out. The
output register is always one clock begind the shift register.
3) Upon hitting "0" (reading of high stop bit) the bit counter's ~{TCD}=~{UART_DR}
goes LOW with the falling edge of CPD, which is also stoping the timer via CET.
The datum *prior* to this last shift remains in the 74HC595's output register
since it is always one step late, and subsequently arriving data have no effect.
4) ~{UART_DR} is sampled by the flags register and fed into the control logic
If ~{UART_DR}=LOW, the microcode of the INP instruction activates TO=TC
5) The received datum is automatically compared to 0xff. Z=1 indicates that
no datum other than 0xff is present.
6) Polling then looks like this:

into the shift register.
We count 10 clock pulses
here (until high stop
bit) since the 74HC595
output register is one
clock pulse late.

1 D2 10 ~{PL} 11 ~{TCU} 12 ~{TCD} 13 MR 14 D0 15 VCC 16 Q1

1 ~{SRCLR}10 SRCLK 11 RCLK 12 ~{OE}13 SER 14 QA 15 VCC 16 QC

used since it has a
synchroneous ~{PL}.

loop: INP BEQ loop ; loop back if 0xff was read

The loop samples (reads and resets) ~{UART_DR} every 11 clock cycles and thus
ensures that a datum can be read before the 2nd stop bit (16 cycles) is over
and the receiver has to be armed again.

~{TCD} goes LOW with the falling edge of CPD,
at the end of the stop bit.

The bit order is intentionally reversed.

Id: 2/11 Title: UART Section

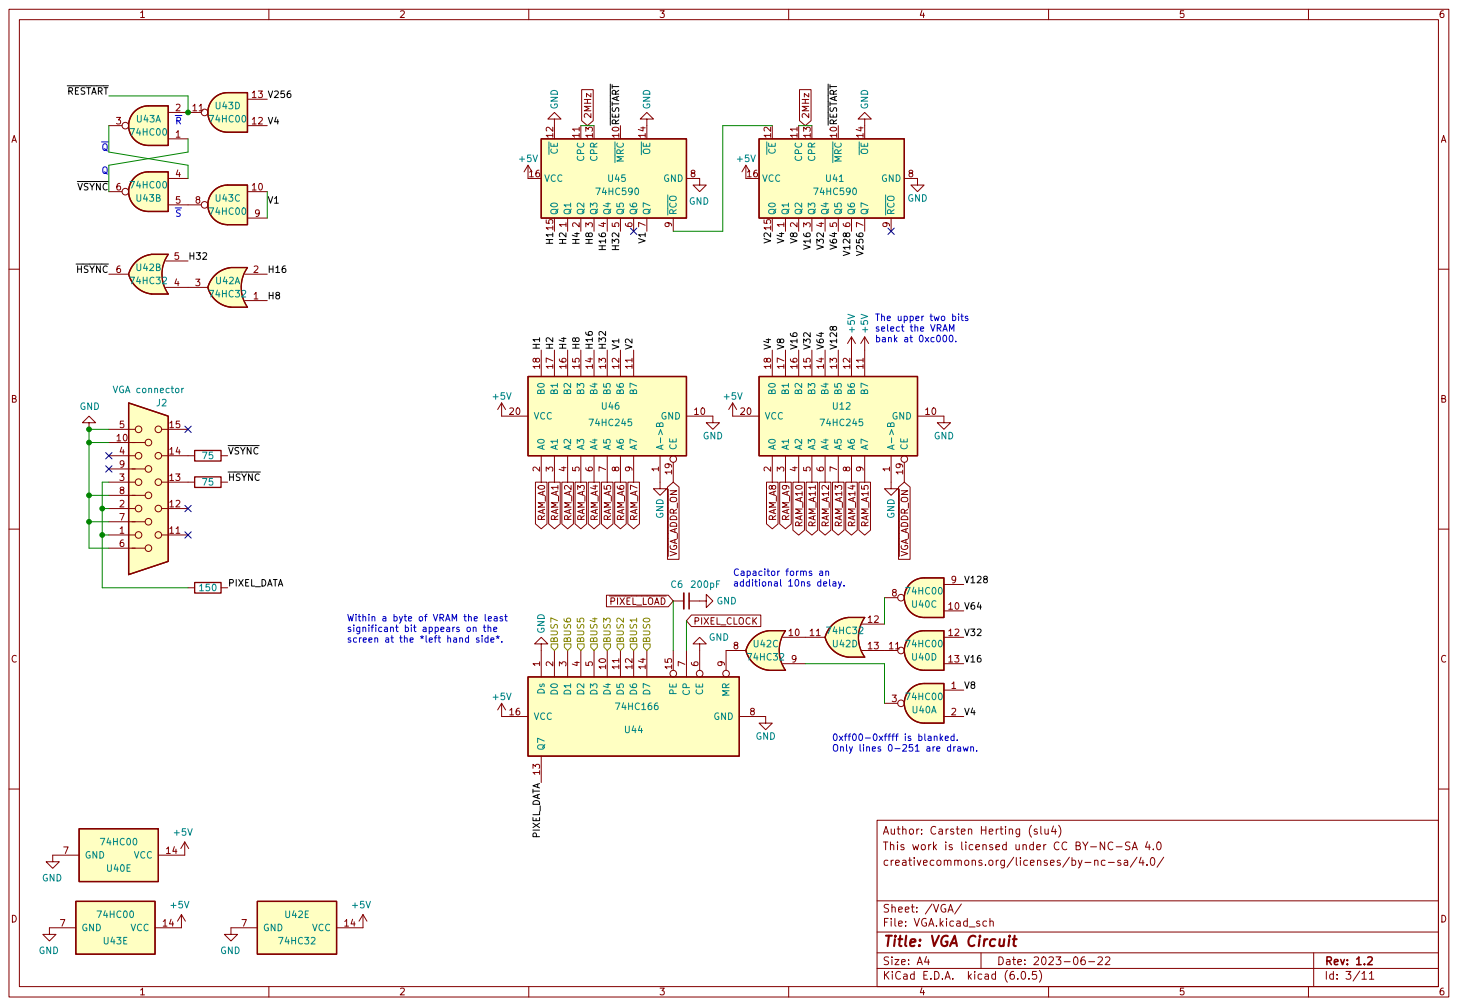
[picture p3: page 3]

select the VRAM bank at 0xc000. ~{Q}

The upper two bits

additional 10ns delay. 0xff00-0xffff is blanked. Only lines 0-251 are drawn.

Within a byte of VRAM the least

Id: 3/11 Title: VGA Circuit

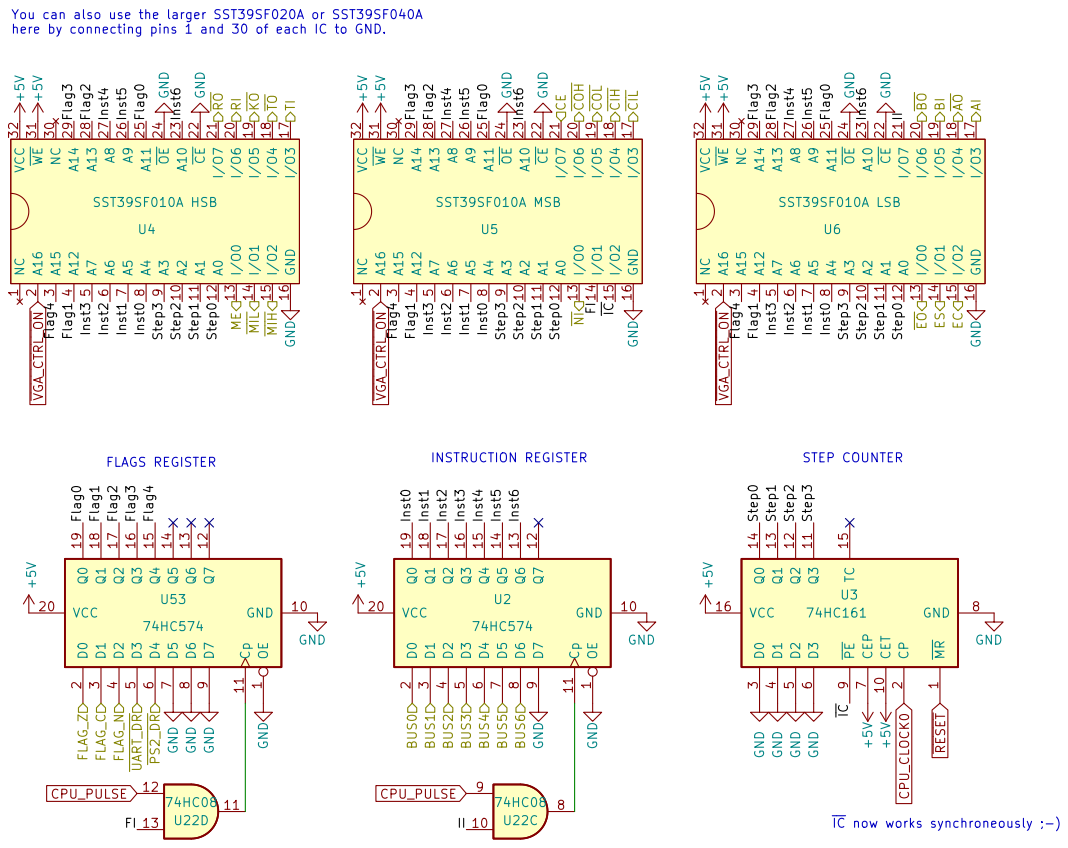
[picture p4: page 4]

You can also use the larger SST39SF020A or SST39SF040A
here by connecting pins 1 and 30 of each IC to GND.

9 U6 SST39SF010A LSB GND GND GND GND RI ~{KO} ~{TO} BUS0 BUS1 BUS3 BUS4 BUS5 FLAG_Z FLAG_C FLAG_N ~{UART_DR} ~{PS2_DR} ~{MIL} ~{MIH} TI BUS2 ~{BO} BI ME ~{RO} ~{AO} AI ~{EO} ESEC BUS6 CE~{COH} ~{COL} ~{CIH} ~{CIL} ~{NI} ~{VGA_CTRL_ON} CPU_PULSE CPU_PULSE CPU_CLOCK0 ~{RESET} ~{VGA_CTRL_ON} ~{VGA_CTRL_ON} Step2 Flag0 Flag2 Flag3 Flag4 Inst0 Inst1 Inst4 Inst6 Inst3 Inst2 Inst0 Step3

9 U5 SST39SF010A MSB GND +5V GND GND GND GND ~{MR} 1 CET 10 Q3 11 Q2 12 Q1 13 Q0 14 TC 15 VCC 16 CP
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

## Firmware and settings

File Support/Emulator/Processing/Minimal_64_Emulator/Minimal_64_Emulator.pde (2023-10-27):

// ------------------------------------------------------------------------------------------------------------------
// 'MINIMAL 64 Home Computer' emulator for Processing - written by Carsten Herting (slu4), last update July 21st 2023
// ------------------------------------------------------------------------------------------------------------------

final int screenWidth = 1024; // set the screen width (original size is 400 x 240 pixels)

byte[] mFlash; byte[] mRam = new byte[0x10000]; // memory of the CPU
int mBank=0, mA=0, mFlags=0, mPC=0; // register states of the CPU

final int[][] keyScancodePairs = // PS2 scan codes (German keyboard layout) (0xE0 codes are omitted since MinOS ignores them anyway)
{ 
  {(int)'A', 0x1C},      {(int)'B', 0x32},      {(int)'C', 0x21},        {(int)'D', 0x23},      {(int)'E', 0x24},
  {(int)'F', 0x2B},      {(int)'G', 0x34},      {(int)'H', 0x33},        {(int)'I', 0x43},      {(int)'J', 0x3B},
  {(int)'K', 0x42},      {(int)'L', 0x4B},      {(int)'M', 0x3A},        {(int)'N', 0x31},      {(int)'O', 0x44},
  {(int)'P', 0x4D},      {(int)'Q', 0x15},      {(int)'R', 0x2D},        {(int)'S', 0x1B},      {(int)'T', 0x2C},
  {(int)'U', 0x3C},      {(int)'V', 0x2A},      {(int)'W', 0x1D},        {(int)'X', 0x22},      {(int)'Y', 0x35},
  {(int)'Z', 0x1A},      {(int)'0', 0x45},      {(int)'1', 0x16},        {(int)'2', 0x1E},      {(int)'3', 0x26},
  {(int)'4', 0x25},      {(int)'5', 0x2E},      {(int)'6', 0x36},        {(int)'7', 0x3D},      {(int)'8', 0x3E},
  {(int)'9', 0x46},      {(int)' ', 0x29},      {(int)',', 0x41},        {(int)'.', 0x49},      {13, 0x5A}, /*ENTER*/
  {27, 0x76}, /*ESC*/    {9, 0x0D}, /*TAB*/     {8, 0x66}, /*BACK*/      {147, 0x71}, /*DEL*/   {150, 0x75}, /*UP*/
  {152, 0x72}, /*DOWN*/  {149, 0x6B}, /*LEFT*/  {151, 0x74}, /*RIGHT*/   {15, 0x12}, /*SHIFT*/  {17, 0x14}, /*CTRL*/
  {18, 0x11}, /*ALT*/    {19, 0x11}, /*ALTGR*/  {2, 0x6C}, /*HOME*/      {3, 0x69}, /*END*/     {16, 0x7D}, /*PG_UP*/
  {11, 0x7A}, /*PG_DN*/  {47, 0x4A}, /*MINUS*/  {92, 0x5D}, /*HASH*/     {93, 0x5B}, /*PLUS*/   {0, 0x61}, /*LESS*/
  {45, 0x4E}, /*BSLASH*/ {96, 0x0E}, /*POWER*/
};

HashMap<Integer, Byte> ps2ScanCodes = new HashMap<Integer, Byte>();
boolean[] keyPressedStates = new boolean[0x100]; // remember state of all keys (for repeat handling)
long[] keyPressedTimestamps = new long[0x100]; // timestamps of keypresses
ArrayList<Byte> serialInput = new ArrayList<Byte>();
ArrayList<Byte> ps2Input = new ArrayList<Byte>();
int serialWaitClocks=0, ps2WaitClocks=0; // emulates the speed of a PS2 or serial sender
int haveClocks=0; // number of cycles to be simulated
int flashState=0; // determines the state of a write operation to FLASH (see SSF39 datasheet)

final int[] clocksPerInstruction = // clock cycles used per instruction
{ 
  16,  4,  4,  6,  5,  5,  4,  6,  6,  5,  5,  5,  5,  5,  6,  7,
   8,  9, 10, 11, 12,  5,  6,  7,  8,  9, 10, 11, 12,  5,  5,  5,
   5,  5,  5,  5,  5, 12,  5,  7,  7,  8,  8,  8,  8,  8,  8,  8,
  15,  8, 10, 10, 11, 11, 11, 11, 11, 11, 11,  8,  9,  9,  9,  9,
   8,  9,  8,  9,  8,  8,  8, 15,  8, 15,  9, 11, 11, 11, 12, 11,
  12, 11, 12, 10, 10, 14, 12, 11,  7,  8, 15,  5,  5,  5,  5,  5,
   5,  5,  5,  6,  6,  7,  7, 10, 12,  7,  7,  7,  7,  7,  7,  7,
  13,  7,  7, 10,  8, 11,  7,  8,  8,  8,  8,  8,  8,  8, 14,  6
};

final int FLAG_Z = 1; // ALU zero flag
final int FLAG_C = 2; // ALU carry flag
final int FLAG_N = 4; // ALU negative flag

// -------------------------------------------------------------------------------------------------

import java.awt.Toolkit; // for clipboard access
import java.awt.datatransfer.*; // for clipboard access
import java.util.HashMap; // for PS2 code hash maps

void settings() { size(screenWidth, screenWidth*240/400, P2D); } // use the fast renderer

void setup()
{
  for(int i=0; i<mRam.length; i++) mRam[i] = (byte)random(256); // randomize RAM content after power-up
  for (int[] p : keyScancodePairs) ps2ScanCodes.put(p[0], (byte)p[1]); // initialize PS2 scan code hash table
  if ((mFlash = loadBytes("flash.bin")) == null || mFlash.length != 0x80000) exit(); // load the flash.bin image into FLASH
  surface.setTitle("Minimal 64 Emulator - F10: PASTE clipboard data, F11: RESET, F12: QUIT");  
}

void draw()
{
  haveClocks += int(6000000/frameRate);
  
  while(haveClocks > 0) haveClocks -= DoInstruction(); // executes instruction and consumes number of clock cycles used
  
  PImage videoRam = new PImage(512, 252); // video RAM
  int videoAddress = 0xc000; // start of first row
  for(int i=0; i<512*252; i+=8) // 64 bytes per row, 252 rows
  {
    byte b = mRam[videoAddress++]; // fetch next byte of VRAM    
//    for(int j=0; j<8; j++) { videoRam.pixels[i+j] = (b & 1) == 1 ? 0xffb0ffd0 : 0xff20282f; b>>=1; }
    for(int j=0; j<8; j++) { videoRam.pixels[i+j] = (b & 1) == 1 ? 0xffb0ffd0 : 0xff20282f; b>>=1; }
  }

  image(videoRam.get(96, 12, 400, 240), 0, 0, width, height); // only project the visible area of VRAM onto the canvas

  if (keyPressed) handleKeyRepeat();
}

// -------------------------------------------------------------------------------------------------

void handleKeyRepeat()
{
  long currentTime = millis();
  for (int i = 0; i < keyPressedStates.length; i++)
  {
    if (keyPressedStates[i] && currentTime - keyPressedTimestamps[i] > 260) // delayTime
    {
      keyPressedTimestamps[i] = currentTime - 260 + 60; // - delayTime + repeatTime
      if (ps2ScanCodes.get(i) != null) ps2Input.add(ps2ScanCodes.get(i));
    }
  }
}
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

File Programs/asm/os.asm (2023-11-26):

; ******************************************************************
; *****                                                        *****
; *****       MinOS 2.0 for the MINIMAL 64 Home Computer       *****
; *****                                                        *****
; ***** written by Carsten Herting - last update: Oct 4th 2023 *****
; *****                                                        *****
; ******************************************************************

; LICENSING INFORMATION
; This file is free software: you can redistribute it and/or modify it under the terms of the
; GNU General Public License as published by the Free Software Foundation, either
; version 3 of the License, or (at your option) any later version.
; This file is distributed in the hope that it will be useful, but WITHOUT ANY WARRANTY; without even the
; implied warranty of MERCHANTABILITY or FITNESS FOR A PARTICULAR PURPOSE. See the GNU General Public
; License for more details. You should have received a copy of the GNU General Public License along
; with this program. If not, see https://www.gnu.org/licenses/.

; HOW TO USE THIS CODE
; This file represents the sourcecode of the operating system 'MinOS 2' of the 'MINIMAL 64'.
; A HEX file of the OS code can be produced by typing 'asm os.asm'. This HEX file can be burned
; into the first 3 banks of the 512KB FLASH SSD ROM of the MINIMAL and will allow it to boot.
; In case a prior version of MinOS is already installed in your hardware, the OS can be updated
; 'in situ': Upload the HEX file into RAM 0x0000-0x2fff by typing 'receive ENTER' and pasting the
; HEX file into a terminal to the MINIMAL 64 via the UART interface. When the upload into RAM has
; completed, type 'flash ENTER' to copy the OS from RAM into FLASH banks 0-2. Upon pressing RESET,
; the new OS will start. Since only banks 0-2 are updated, user files will remain on the SSD.

; By default FLASH is deaktivated by the OS (BANK = 0xff) yielding contiguous RAM 0x0000-0xffff.
; Only during file access FLASH is activ.

; _<label> are API labels providing access to kernel functions & data via a jump table. They will not change.

; **********************************************************************************************************

#org 0x0000                                                    ; Bank 0, Address 0 = entry point after RESET

OS_Bootloader:  LDI <OS_Image_Start STA 0xfffc                 ; prepare OS image address at 0xfffc/d
                LDI >OS_Image_Start STA 0xfffd
                LDI <_Start STA 0xfffe                         ; prepare OS target address at 0xfffe/f
                LDI >_Start STA 0xffff

  imcopyloop:   LDR 0xfffc STR 0xfffe                          ; copy the OS image to RAM
                INW 0xfffc INW 0xfffe
                
                LDA 0xfffe CPI <OS_Image_End BNE imcopyloop    ; destination address beyond OS kernel?
                  LDA 0xffff CPI >OS_Image_End BCC imcopyloop

; **********************************************************************************************************

OS_Image_Start:                                                ; OS image starts HERE on bank 0

  #mute                                                        ; do not emit origin address...
  #org 0xb000                                                  ; ... but assemble for this destination
  #emit                                                        ; begin emitting code here

  ; KERNEL JUMP TABLE
  _Start:         JPA OS_Start
  _Prompt:        JPA OS_Prompt
  _ReadLine:      JPA OS_ReadLine
  _ReadSpace:     JPA OS_ReadSpace
  _ReadHex:       JPA OS_ReadHex
  _SerialWait:    JPA OS_SerialWait
  _SerialPrint:   JPA OS_SerialPrint
  _FindFile:      JPA OS_FindFile
  _LoadFile:      JPA OS_LoadFile
  _SaveFile:      JPA OS_SaveFile
  _MemMove:       JPA OS_MemMove
  _Random:        JPA OS_Random
  _ScanPS2:       JPA OS_ScanPS2
  _ReadInput:     JPA OS_ReadInput
  _WaitInput:     JPA OS_WaitInput
  _ClearVRAM:     JPA OS_ClearVRAM
  _Clear:         JPA OS_Clear
  _ClearRow:      JPA OS_ClearRow
  _SetPixel:      JPA OS_SetPixel
  _ClrPixel:      JPA OS_ClrPixel
  _GetPixel:      JPA OS_GetPixel
  _Char:          JPA OS_Char
  _Line:          JPA OS_Line
  _Rect:          JPA OS_Rect
  _Print:         JPA OS_Print
  _PrintChar:     JPA OS_PrintChar
  _PrintHex:      JPA OS_PrintHex
  _ScrollUp:      JPA OS_ScrollUp
  _ScrollDn:      JPA OS_ScrollDn
  _ResetPS2:      JPA OS_ResetPS2

OS_Start:       LDI 0xfe STA 0xffff                            ; switch off FLASH and init stack

                LDI <uarttxt PHS LDI >uarttxt PHS              ; send start screen via UART
                JPS OS_SerialPrint PLS PLS

                JPS OS_ClearVRAM                               ; show VGA start screen
                JPS OS_Logo                                    ; show 'Minimal' logo
                LDI 15 STA _XPos LDI 1 STA _YPos               ; display splash screen text
                LDI <logotxt1 PHS LDI >logotxt1 PHS
                JPS OS_Print PLS PLS
                LDI 15 STA _XPos
                LDI <logotxt2 PHS LDI >logotxt2 PHS
                JPS OS_Print PLS PLS
                LDI 15 STA _XPos
                LDI <logotxt3 PHS LDI >logotxt3 PHS
                JPS OS_Print PLS PLS

  OS_Prompt:    BFF LDI 0xfe STA 0xffff                        ; re-init stack
                LDI <readytxt PHS LDI >readytxt PHS            ; display 'READY.'
                JPS OS_Print PLS PLS

  newline:      LDI <_ReadBuffer STA _ReadPtr+0                ; parse a line of user input
                LDI >_ReadBuffer STA _ReadPtr+1
                JPS OS_ReadLine                                ; MAIN LOOP: read in a line of user input
                JPS OS_ReadSpace                               ; omit leading spaces
                LDR _ReadPtr CPI 10 BEQ newline                ; empty line?
                  JPS OS_LoadFile CPI 0 BEQ OS_Error           ; load the file (=instruction)
                    JPR PtrD                                   ; run a loaded program with command line ptr on stack

  OS_Error:     LDI <errortxt PHS LDI >errortxt PHS JPS OS_Print
                JPA OS_Prompt

  uarttxt:      27, '[H', 27, '[J', 27, '[?25h'                ; HOME, CLR, SHOW CURSOR + "READY." below
  readytxt:     'READY.', 10, 0
  errortxt:     'NOT FOUND.', 10, 0
  logotxt1:     '*****  M I N I M A L  6 4  *****', 10, 10, 0
  logotxt2:     '64KB RAM - 512KB SSD - MinOS 2.0', 10, 10, 0
  logotxt3:     'Type ', 39, 'show manual', 39, ' for more info', 10, 10, 0
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

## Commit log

2023-07-08 Revision 1.2
    [8-Bit CPU 32k.dsn, 8-Bit CPU 32k.kicad_sch, 8-Bit CPU 32k.sch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]
2023-07-13 Link to BOM added

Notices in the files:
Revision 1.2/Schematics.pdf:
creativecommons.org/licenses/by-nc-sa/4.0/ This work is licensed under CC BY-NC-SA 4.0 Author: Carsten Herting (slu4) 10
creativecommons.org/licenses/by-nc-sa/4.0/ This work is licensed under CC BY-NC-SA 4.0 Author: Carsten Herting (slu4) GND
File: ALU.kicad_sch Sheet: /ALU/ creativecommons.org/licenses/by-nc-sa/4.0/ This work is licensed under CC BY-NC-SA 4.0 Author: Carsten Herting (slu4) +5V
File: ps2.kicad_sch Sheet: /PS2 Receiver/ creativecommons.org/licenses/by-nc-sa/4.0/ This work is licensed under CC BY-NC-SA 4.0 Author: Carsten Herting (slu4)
